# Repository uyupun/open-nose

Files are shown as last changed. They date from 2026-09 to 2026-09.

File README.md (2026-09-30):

# OpenNose

- 鼻栓の民主化プロジェクト
- 鼻に詰めたティッシュ(鼻栓)を、「隠すもの」から「装うもの」へ。鼻栓を、身近なものにする
- 簡略化した鼻モデルと遺伝的アルゴリズム(NSGA-II)で、形のトレードオフ(パレート最適)を探る
- 現在の主案は[水引型](#水引型現在の主案)(`scripts/mizuhiki/`)。鼻ピアス型・ゼンマイ型・拡張ブリッジ型・元の設計は、これまでに試した方向

## 構成

```
scripts/
  commons/     # 設計に依らず共通で使うもの
    nose_model.py        # 簡略化した鼻本体モデル(NoseParams)
    plug_model.py        # 鼻栓(ティッシュ等)のプレースホルダー(PlugParams)
    rounded_triangle.py  # 鼻の断面(角丸三角形)の2D幾何プリミティブ
    viewer.py            # ビューア補助(半透明の描画順・カメラ調整)
    report.py            # NSGA-IIの結果表示(世代推移の図・パレートフロントの表)
  earrings/    # 鼻ピアス型(「b」字)フレーム: 片方の鼻ごとに独立したクリップ
    frame_model.py       # 形状(FrameParamsの6変数): 鼻翼を挟むリング + 鼻栓に刺すステム
    evaluation.py        # 評価関数(3目的 + 制約)
    scene.py             # 鼻本体・鼻栓・フレームを1つのSceneにまとめる
    optimize.py / export_model.py / export_frame.py / view_nose.py
  spiral/      # ゼンマイ(渦巻き)型フレーム: 鼻翼の外側にぶら下がるコイル + 鼻栓に刺すステム
    frame_model.py       # 形状(FrameParamsの6変数): 渦巻きのコイル + ステム
    evaluation.py        # 評価関数(3目的 + 制約)
    scene.py             # 鼻本体・鼻栓・フレームを1つのSceneにまとめる
    optimize.py / export_model.py / export_frame.py / view_nose.py
  dilator/     # 拡張ブリッジ型フレーム: 鼻腔拡張テープ(ブリーズライト等)のように鼻を押し開く平らなブリッジ + 鼻栓を受け入れる筒
    frame_model.py       # 形状(FrameParamsの8変数): 鼻の前面と側面に沿って横断する平らな薄いブリッジ(両端は巻き込まずまっすぐ伸ばし、両面テープの貼り代にする。印刷するときは同じアーチを少し開いた自然な形) + 左右の棒(アーチと同じ板の断面で、アーチの面からリングの面へねじれる平たいブレード。鼻翼の輪郭に沿って鼻孔まで約31mm) + 左右のリング(鼻中隔側を開いたC字の筒)(印刷・装着しやすいよう3部品に分け、脚の上端の小さなC字が帯の上下の縁を抱いて連結する)
    evaluation.py        # 評価関数(3目的: 拡張力・鼻栓の保持剛性・目立たなさ + 制約16個)
    scene.py             # 鼻本体・鼻栓・フレームを1つのSceneにまとめる
    optimize.py / export_model.py / export_frame.py / view_nose.py
  mizuhiki/    # 水引型: 丸めたティッシュ(鼻栓)に着け、3本の紐の帯がティッシュを1周する輪から小鼻の外側へ上がって、あわじ結び(三つ輪)になる器具。結びを小鼻の前寄り(鼻の側面)に置き、正面からも横顔からも水引と読める。濃い色で刷ると、結びが鼻の穴の両脇を縁取り、小鼻の輪郭にも見える
    frame_model.py       # 形状(MizuhikiParamsの5変数: 結びの大きさ・高さ・小鼻の上の位置、紐の太さ、端の長さ)。紐の肌の側をつなぐ板と、輪の底を平らに削る補強でFDMで刷れる
    evaluation.py        # 評価関数(3目的: 横顔での存在感・正面での読みやすさ・ティッシュをつかむ面積 + 制約13個)
    scene.py             # 鼻本体・鼻栓・器具を1つのSceneにまとめる
    optimize.py / export_model.py / export_frame.py / view_nose.py
  models/      # 元の設計: 鼻中隔付近のアーム + 鼻栓へ向かうコネクタ(両鼻を同時に挟む)
    frame_model.py / scene.py
  evaluation.py / optimize.py / optimize_report.py
  export_model.py / export_frame.py / view_nose.py   # 元の設計のスクリプト
output/
  models/    # 元の設計の出力(base.glb, evolution.png, candidate_*.glb)
  earrings/  # 鼻ピアス型の出力(base.glb, evolution.png, candidate_*.glb, 印刷用 *_frame_{left,right}.stl)
  spiral/    # ゼンマイ型の出力(base.glb, evolution.png, candidate_*.glb, 印刷用 *_frame_{left,right}.stl)
  mizuhiki/  # 水引型の出力(base.glb, evolution.png, pareto.csv, candidate_*.glb, 印刷用 *_{left,right}_print.stl)
  dilator/   # 拡張ブリッジ型の出力(base.glb, evolution.png, candidate_*.glb, 印刷用 *_frame_bridge.stl / *_frame_leg_left.stl / *_frame_leg_right.stl)
```

新しい設計を足すときは、`earrings/`と同じ構成(frame_model・evaluation・scene・各スクリプト)のフォルダを`scripts/`直下に作り、鼻本体・鼻栓・ビューア・レポートは`commons/`のものを使う。

## 水引型(現在の主案)

丸めたティッシュ(鼻栓)に着ける小さな器具。3本の紐を平らに並べた帯がティッシュのまわりを1周して輪になり(輪にティッシュを通して留める)、小鼻の外側を上がって、あわじ結び(三つ輪)になる。結びの下からは端が垂れる。

水引は、ご祝儀袋やお見舞いの包みで誰もが目にする結びで、性別を問わず使われる。鼻栓に水引を添えることで、見られたくないものを、見覚えのある贈り物の飾りに変える。ティッシュを通す輪だけの形(鼻の下のキャップ)は人の目に留まらず、見え方を変えられなかったので、結びを小鼻の上に出して見せている。

- **結びの位置**: 小鼻の横ではなく、正面を斜めに向いた鼻の側面に置く。最初の試作を着けてみると、小鼻の横の結びは正面から真横に見えて、三つ輪がつぶれて読めなかった。人に見られるのはほとんど正面からなので、正面から水引と分かる位置に出した。結びの内側の端は、正面から見て鼻の穴の中心の線までに収め、鼻頭には乗せない
- **色**: 濃い色(焦げ茶・濃紺など)で刷ると、結びが鼻の穴の両脇を縁取り、小鼻の輪郭にも見える(見立て)。黒は水引では弔事(黒白)の色なので、描画では焦げ茶にしている
- **大きさ**: 結びの大きさは評価関数では決めず、見た目の塩梅で決める。どの目的も「大きいほど見える」ので、探索させると上限に張り付くため。いまは最初に刷った形の1.1倍(`optimize.py --knot-scale`で変えられる)

### 評価関数(`scripts/mizuhiki/evaluation.py`)

目的は3つで、いずれも大きいほど良い。

| 目的 | 測るもの |
|---|---|
| 横顔での存在感 | 真横から見える、輪より上(渡り・結び・端)の面積 |
| 正面での読みやすさ | 正面から見える、結びと端の面積 |
| ティッシュをつかむ面積 | 輪の内側の面積(紐が太いほど輪が高く、よくつかむ) |

見える面積は、鼻の陰に隠れる部分を除いて測る。結びの位置が小鼻の横に寄るほど横顔で、鼻の側面に寄るほど正面で見え、この向きが1つ目と2つ目のトレードオフになる。

制約は13個で、すべて満たす形だけを候補にする。

- 結びが読める: 三つ輪の穴が、横顔からも正面からも抜けて見える(紐を太く・結びを小さくすると穴が潰れる)
- 鼻頭に乗らない: 正面から見て、結びの内側の端が鼻の穴の中心の線を越えない
- 肌・顔との関係: 紐が肌に近づきすぎない、結びが肌から浮かず小鼻の面に乗る、頬に当たらない、小鼻の上端を越えない、鼻の下へ垂れない、左右の器具が当たらない
- FDM(0.4mmノズル)で刷れる: 紐の直径0.8mm以上、紐のつなぎ目の厚み0.6mm以上、輪の底がベッドに着く面積

閾値はいずれも暫定値で、刷って着けながら見直していく。

### いまのおすすめ

`candidate_frontal`(結びの大きさ1.74・高さ2.30・位置1.30・紐の半径0.455mm)。最初に刷った形(小鼻の横に結び)と比べて、正面での読みやすさが約2.4倍(27.8→67.2mm^2)になり、横顔での存在感はほぼ保っている(85.2→80.5mm^2)。結びの内側の端は、鼻の穴の中心の線の0.65mm手前。

`output/mizuhiki/base.glb`(既定値の形)は、最初に手で決めた形のまま。いまの評価では、結びの後ろの輪が頬に当たり、正面から三つ輪が読めない。

### 刷り方(Bambu Studio・FDM 0.4mmノズル)

試作はPLAで刷っている。器具は左右とも約15×16×14mm、片側約0.2g。

- **STL**: `candidate_frontal_left_print.stl`・`candidate_frontal_right_print.stl`。輪の底面をベッドに置き、着けたときの上を上にした向きで書き出してある(6方向を比べて、サポートの要る面が最も少ない向き)。読み込んだ向きのまま使い、自動配置はしない
- **品質**: 層の高さ0.12mm前後、壁生成はArachne(0.6mm前後の紐のつなぎ目を1本の線に丸めずに出す)
- **ブリム**: 外側のみ、幅3〜5mm。ベッドに着くのは輪の底の細い環だけなので
- **冷却**: 左右を離して並べ、冷却のため速度を落とす設定をオンにする(小さい部品は1層がすぐ終わり、冷えきらずにだれる)
- **サポート**: タイプを「ツリー(手動)」にし、サポートペイント(L)で、次の3か所の紐の下側だけを強制で塗る(左右それぞれ)。どれも真下はベッドまで空いているので、「ビルドプレートのみ」はオンでよい
  - 結びから垂れる端の先(高さ約1.7mm)
  - 結びの下の輪のいちばん下(高さ約3.3mm)
  - 結びの上の輪の張り出し(高さ約8.6〜9.0mm)

  自動にすると、三つ輪の中の1mm前後の橋渡し(支えなしで刷れる)にまで枝が入り込み、外しにくく紐を折りやすい。塗る場所は、一度スライスしてプレビューの層スライダーを上の高さに合わせると、宙に浮いて始まる紐として見つかる
- **サポートの外し方**: 完全に冷めてから、ベッド側の太い幹を先にニッパーで切り、紐に付いた先端は、その紐のすぐ横を押さえて小さく揺らして外す。器具は太い輪の部分を持ち、結びは持たない

## Scripts

### 共通

```bash
# 依存パッケージをインストール
$ uv sync
```

### 鼻ピアス型(earrings)

```bash
# 鼻本体・鼻栓・フレームの既定構成一式を生成して output/earrings/base.glb に出力
$ uv run python scripts/earrings/export_model.py

# 生成した鼻モデルをインタラクティブビューアで確認(引数なしで既定形状)
$ uv run python scripts/earrings/view_nose.py

# NSGA-IIでフレーム形状を最適化し、output/earrings/evolution.png に出力(パレートフロントは標準出力の表で確認)
# --sort-by {retention,pain,visibility} で表の並び順を変えられる(ある目的に極振りした候補を先頭から拾う用)
$ uv run python scripts/earrings/optimize.py
$ uv run python scripts/earrings/optimize.py --sort-by visibility

# 上の表から選んだ行の6変数(ring_r ring_gap ring_t ring_d stem_len stem_t)をglTF(.glb)に出力
# (base.glbは上書きしない。ファイル名は実行時刻から自動生成、--output-nameで指定も可)
$ uv run python scripts/earrings/export_frame.py --ring-radius 3.04 --ring-gap-deg 92.13 --ring-thickness 2.47 --ring-depth 0.85 --stem-length 3.84 --stem-thickness 1.09 --output-name candidate_balanced.glb

# --stl を付けると、フレーム(左右)だけを3Dプリント用STLとしても書き出す
# (output/earrings/<出力名>_frame_left.stl / _frame_right.stl、単位mm)
$ uv run python scripts/earrings/export_frame.py --ring-radius 3.04 --ring-gap-deg 92.13 --ring-thickness 2.47 --ring-depth 0.85 --stem-length 3.84 --stem-thickness 1.09 --output-name candidate_balanced.glb --stl

# 出力した候補(glb)や、フレーム単体のSTLをインタラクティブビューアで確認
$ uv run python scripts/earrings/view_nose.py output/earrings/candidate_balanced.glb
$ uv run python scripts/earrings/view_nose.py output/earrings/candidate_balanced_frame_left.stl
```

### ゼンマイ型(spiral)

```bash
# 鼻本体・鼻栓・フレームの既定構成一式を生成して output/spiral/base.glb に出力
$ uv run python scripts/spiral/export_model.py

# 生成した鼻モデルをインタラクティブビューアで確認(引数なしで既定形状)
$ uv run python scripts/spiral/view_nose.py

# NSGA-IIでフレーム形状を最適化し、output/spiral/evolution.png に出力(パレートフロントは標準出力の表で確認)
# --sort-by {visibility,weight,turns} で表の並び順を変えられる(ある目的に極振りした候補を先頭から拾う用)
$ uv run python scripts/spiral/optimize.py
$ uv run python scripts/spiral/optimize.py --sort-by weight

# 上の表から選んだ行の6変数(turns start_r end_r coil_t stem_t stem_len)をglTF(.glb)に出力
# (base.glbは上書きしない。ファイル名は実行時刻から自動生成、--output-nameで指定も可)
$ uv run python scripts/spiral/export_frame.py --turns 0.73 --start-radius 7.42 --end-radius 2.95 --coil-thickness 1.80 --stem-thickness 0.58 --stem-length 8.06 --output-name candidate_balanced.glb

# --stl を付けると、フレーム(左右)だけを3Dプリント用STLとしても書き出す
# (output/spiral/<出力名>_frame_left.stl / _frame_right.stl、単位mm)
$ uv run python scripts/spiral/export_frame.py --turns 0.73 --start-radius 7.42 --end-radius 2.95 --coil-thickness 1.80 --stem-thickness 0.58 --stem-length 8.06 --output-name candidate_balanced.glb --stl

# 出力した候補(glb)や、フレーム単体のSTLをインタラクティブビューアで確認
$ uv run python scripts/spiral/view_nose.py output/spiral/candidate_balanced.glb
$ uv run python scripts/spiral/view_nose.py output/spiral/candidate_balanced_frame_left.stl
```

### 拡張ブリッジ型(dilator)

```bash
# 鼻本体・鼻栓・フレームの既定構成一式を生成して output/dilator/base.glb に出力
$ uv run python scripts/dilator/export_model.py

# 生成した鼻モデルをインタラクティブビューアで確認(引数なしで既定形状)
$ uv run python scripts/dilator/view_nose.py

# NSGA-IIでフレーム形状を最適化し、output/dilator/evolution.png に出力(パレートフロントは標準出力の表で確認)
# --sort-by {extension_force,plug_hold,inconspicuousness} で表の並び順を変えられる(ある目的に極振りした候補を先頭から拾う用)
$ uv run python scripts/dilator/optimize.py
$ uv run python scripts/dilator/optimize.py --sort-by plug_hold

# 上の表から選んだ行の8変数(nat_r tab_pos bridge_y bridge_w bridge_t leg_t collar_l detent。detentは--cuff-detent)をglTF(.glb)に出力
# (base.glbは上書きしない。ファイル名は実行時刻から自動生成、--output-nameで指定も可)
$ uv run python scripts/dilator/export_frame.py --natural-radius 25.96 --tab-side-ratio 1.20 --bridge-y 14.99 --bridge-width 4.06 --bridge-thickness 1.40 --leg-thickness 3.32 --collar-length 2.08 --cuff-detent 0.12 --output-name candidate_balanced.glb

# --stl を付けると、フレームを3Dプリント用STLとしても書き出す。印刷しやすい
# ように、ブリッジ(鼻筋のアーチ状の帯)・左の脚(棒とリング)・右の脚(棒と
# リング)の3つの別々のファイルになる(output/dilator/<出力名>_frame_bridge.stl・
# _frame_leg_left.stl・_frame_leg_right.stl、単位mm)。ブリッジのSTLは、装着
# した形そのものではなく、同じアーチの曲がりを弱めた(少し開いた)自然な形で、
# 鼻の上で曲げて両端を医療用両面テープで貼ると、曲げ戻ろうとする力がブリーズ
# ライトのように小鼻を引き上げる。帯は鼻の前面の丸みと側面に沿うアーチで、両端は
# 鼻の角に沿って巻き込まず、側面の向きのまままっすぐ伸びる(長さ約27mm)。脚は
# それぞれ別々にプリントし、帯を抱くCで組み立てる: 脚の上端は棒と同じ幅の小さな
# C字で、帯の上下の縁に掘ったV溝に爪を入れて帯を抱く。帯の端から滑り込ませ、端寄りの
# 浅い段をカチッと越えると止まる(テープを貼った後でも付け外しできる。爪は帯の厚みの
# 内側で止まり、肌と帯の間には入らない)。
# 棒は鼻の側面を小鼻の外側の輪郭(鼻翼)に沿って降り、鼻中隔側を開いたC字のリングに
# つながる。この設計では鼻栓は鼻の下端から約6.5mm
# 飛び出している想定で、リングはその露出端を掴む
$ uv run python scripts/dilator/export_frame.py --natural-radius 25.96 --tab-side-ratio 1.20 --bridge-y 14.99 --bridge-width 4.06 --bridge-thickness 1.40 --leg-thickness 3.32 --collar-length 2.08 --cuff-detent 0.12 --output-name candidate_balanced.glb --stl

# 出力した候補(glb)や、部品単体のSTLをインタラクティブビューアで確認
$ uv run python scripts/dilator/view_nose.py output/dilator/candidate_balanced.glb
$ uv run python scripts/dilator/view_nose.py output/dilator/candidate_balanced_frame_bridge.stl
```

### 水引型(mizuhiki)

```bash
# 鼻本体・鼻栓・器具の既定構成一式(最初に手で決めた水引の形)を生成して output/mizuhiki/base.glb に出力
$ uv run python scripts/mizuhiki/export_model.py

# 生成した鼻モデルをインタラクティブビューアで確認(引数なしで既定形状)
$ uv run python scripts/mizuhiki/view_nose.py

# NSGA-IIで結びの高さ・小鼻の上の位置・紐の太さを最適化する(40個体×40世代で約7分)。結びの大きさは
# 探索せず --knot-scale で与える(既定1.74)。目的は横顔での存在感・正面での読みやすさ・ティッシュを
# つかむ面積の3つ、制約は13個(scripts/mizuhiki/evaluation.py)。output/mizuhiki/ に次を出力する:
#   evolution.png(世代ごとの分布推移)、pareto.csv(パレートフロントの全個体の変数・目的・制約)、
#   candidate_presence.glb(横顔での存在感が最大)・candidate_frontal.glb(正面で最も読みやすい)・
#   candidate_balanced.glb(3つの目的をパレートフロントの中で0〜1にそろえ、理想点に最も近いもの。
#   目的の差が小さいと、わずかな差に引っ張られるので、表やpareto.csvと見比べて選ぶ)
# パレートフロントの表は標準出力にも出る。--sort-by {profile_presence,frontal_legibility,tissue_grip} で並び順を変えられる
$ uv run python scripts/mizuhiki/optimize.py
$ uv run python scripts/mizuhiki/optimize.py --knot-scale 1.6

# 設計変数を指定してglTF(.glb)に出力し、評価関数の結果(目的3つと制約13個の合否)を表示する。
# 引数を省略した変数は既定値。上の表やpareto.csvから選んだ行の値を渡す(base.glbは上書きしない。
# ファイル名は実行時刻から自動生成、--output-nameで指定も可)
$ uv run python scripts/mizuhiki/export_frame.py
$ uv run python scripts/mizuhiki/export_frame.py --knot-scale 1.74 --knot-y 2.3006 --knot-f 1.2960 --cord-radius 0.4553 --output-name candidate_frontal

# --print を付けると、器具(左右)をそのまま刷れる向き(輪の底面をベッドに置き、着けたときの上を上にする)の
# STLとしても書き出す(<出力名>_left_print.stl / _right_print.stl、単位mm)。FDM(0.4mmノズル)向けに、並べた
# 紐の肌の側を板でつなぎ(つなぎ目の厚み0.6mm以上)、輪の底を0.2mm平らに削ってある。刷るときはツリー
# サポート(手動で3か所を塗る。上の「刷り方」参照)とブリムを使う。--stl で鼻に着けた向きのSTLも書き出せる
$ uv run python scripts/mizuhiki/export_frame.py --knot-scale 1.74 --knot-y 2.3006 --knot-f 1.2960 --cord-radius 0.4553 --output-name candidate_frontal --print

# 出力した候補(glb)や、器具単体のSTLをインタラクティブビューアで確認
$ uv run python scripts/mizuhiki/view_nose.py output/mizuhiki/candidate_frontal.glb
$ uv run python scripts/mizuhiki/view_nose.py output/mizuhiki/candidate_frontal_right_print.stl
```

### 元の設計(アーム + コネクタ)

```bash
# 鼻本体・鼻栓・フレームの既定構成一式を生成して output/models/base.glb に出力
$ uv run python scripts/export_model.py

# 生成した鼻モデルをインタラクティブビューアで確認
$ uv run python scripts/view_nose.py

# NSGA-IIでフレーム形状を最適化し、output/models/evolution.png に出力(パレートフロントは標準出力の表で確認)
$ uv run python scripts/optimize.py

# 上の表から選んだ候補(11変数)をglTF(.glb)に出力(base.glbは上書きしない)
$ uv run python scripts/export_frame.py --connector-heading 24 --connector-length-1 5.5 --arm-thickness 2.0 --holder-offset 12 --grip-depth 0.5

# 出力した候補をインタラクティブビューアで確認
$ uv run python scripts/view_nose.py output/models/candidate_balanced.glb
```

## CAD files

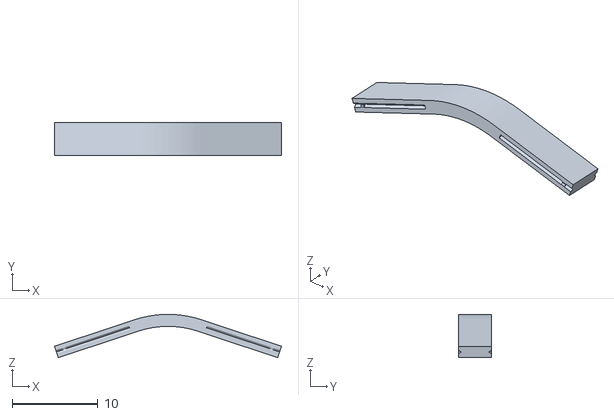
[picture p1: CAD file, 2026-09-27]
output/dilator/connector_cuff_frame_bridge.stl
26.5 x 3.81 x 5.05

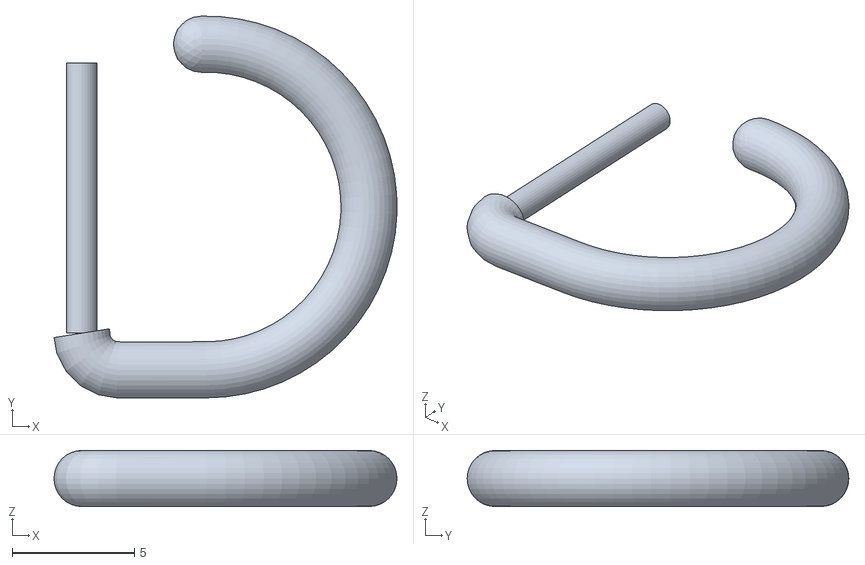
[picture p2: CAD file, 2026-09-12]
output/earrings/candidate_balanced_frame_right.stl
14.0 x 15.6 x 2.30

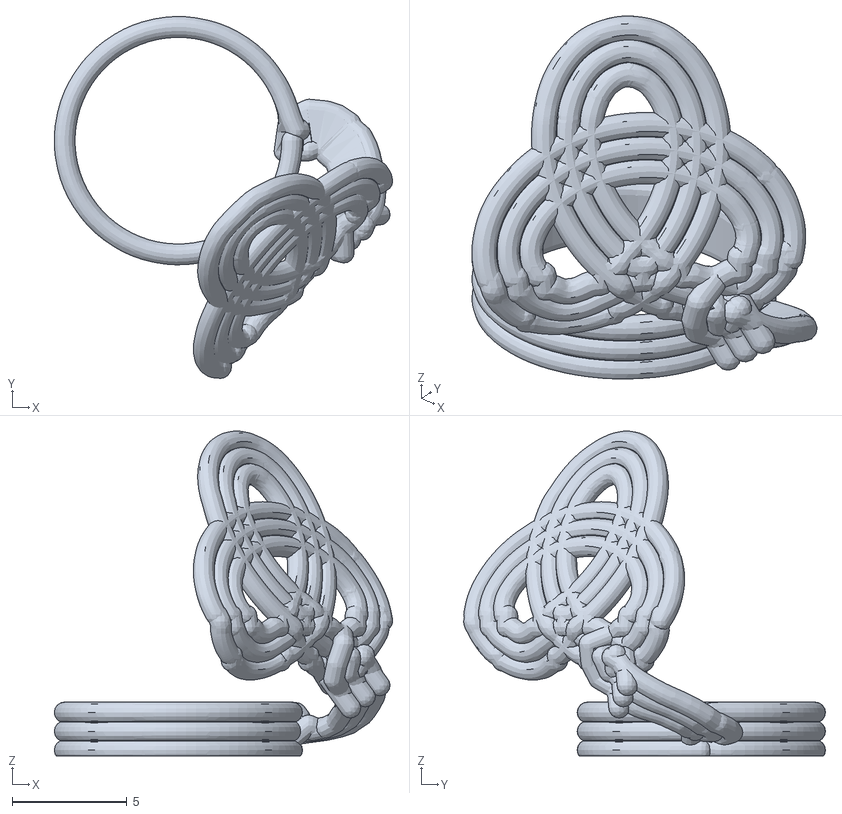
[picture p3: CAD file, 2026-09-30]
output/mizuhiki/candidate_frontal_right_print.stl
14.7 x 15.8 x 14.2

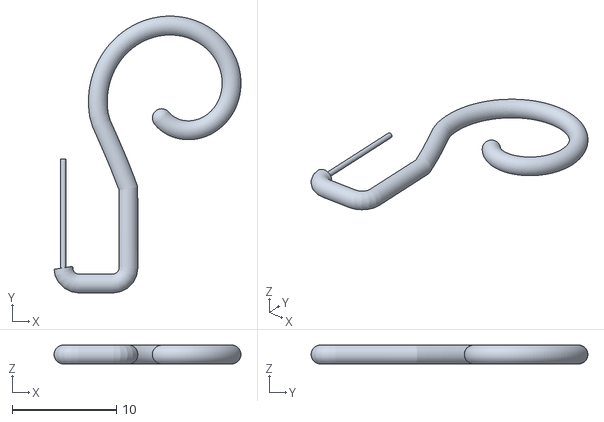
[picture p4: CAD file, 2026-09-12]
output/spiral/candidate_high_visibility_frame_right.stl
17.9 x 26.5 x 1.81

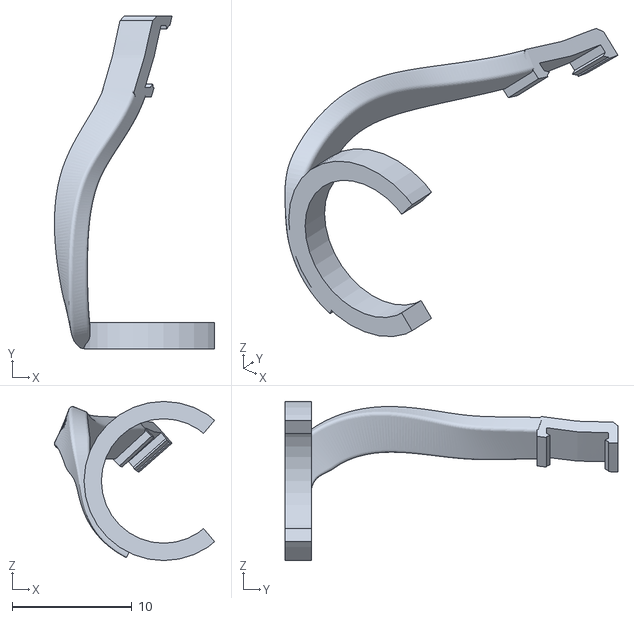
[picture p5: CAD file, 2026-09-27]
output/dilator/candidate_high_force_frame_leg_left.stl
13.4 x 27.8 x 13.3

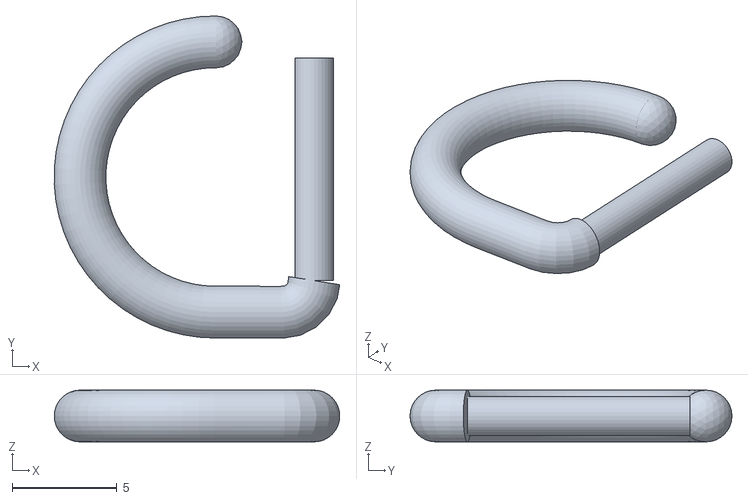
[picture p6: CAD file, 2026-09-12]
output/earrings/candidate_high_retention_frame_left.stl
13.6 x 15.3 x 2.47

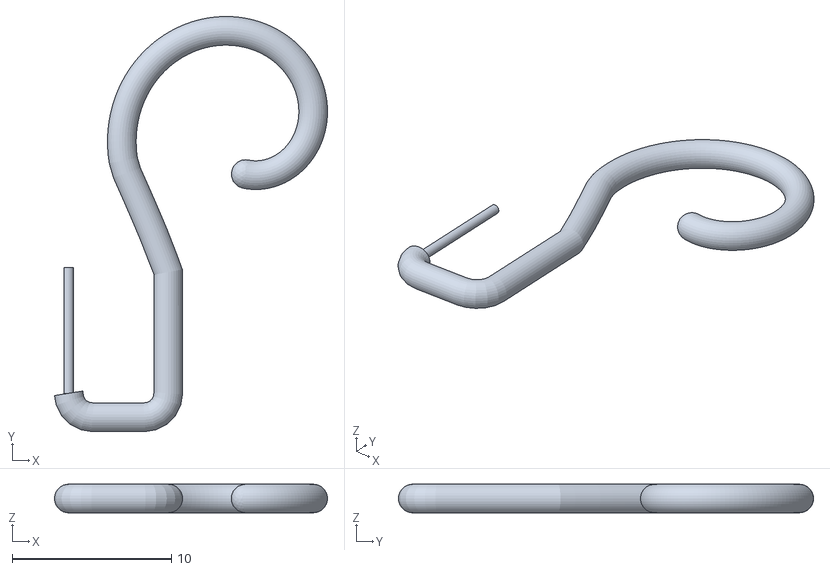
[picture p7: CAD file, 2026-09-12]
output/spiral/candidate_balanced_frame_right.stl
17.1 x 26.0 x 1.80

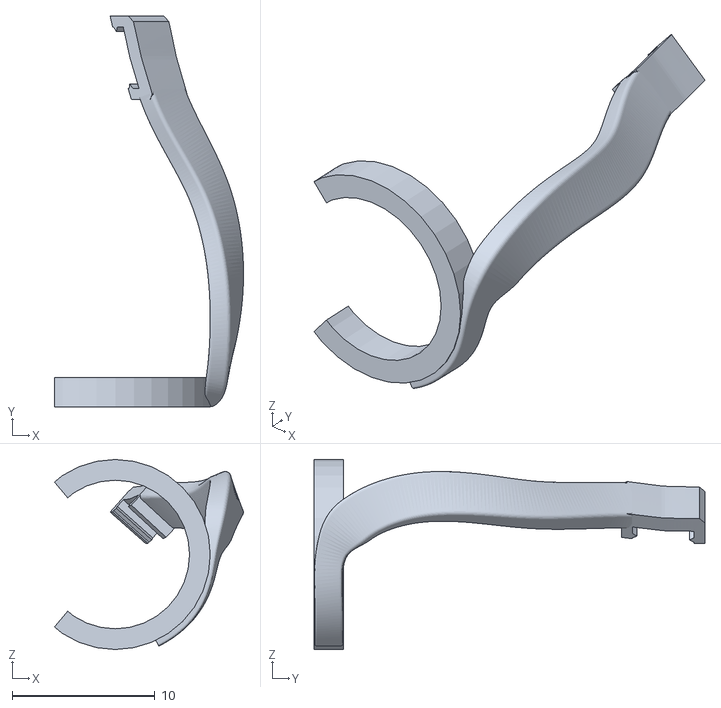
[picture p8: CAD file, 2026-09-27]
output/dilator/candidate_balanced_frame_leg_right.stl
13.2 x 27.4 x 13.3

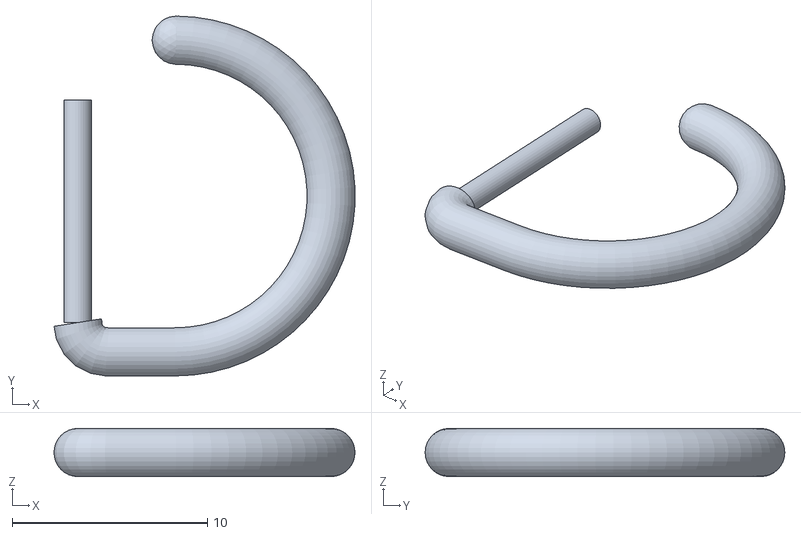
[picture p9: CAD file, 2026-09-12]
output/earrings/candidate_low_pain_frame_right.stl
15.4 x 18.4 x 2.47

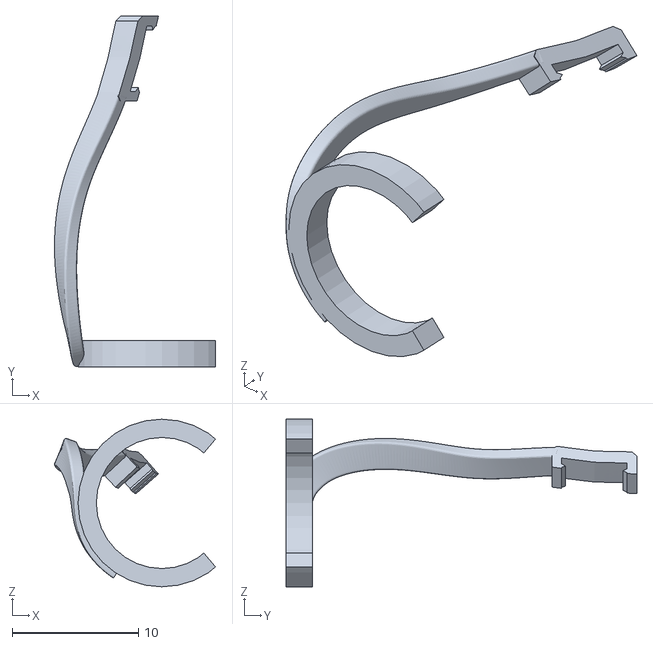
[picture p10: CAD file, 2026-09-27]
output/dilator/candidate_inconspicuous_frame_leg_left.stl
12.8 x 27.8 x 13.3

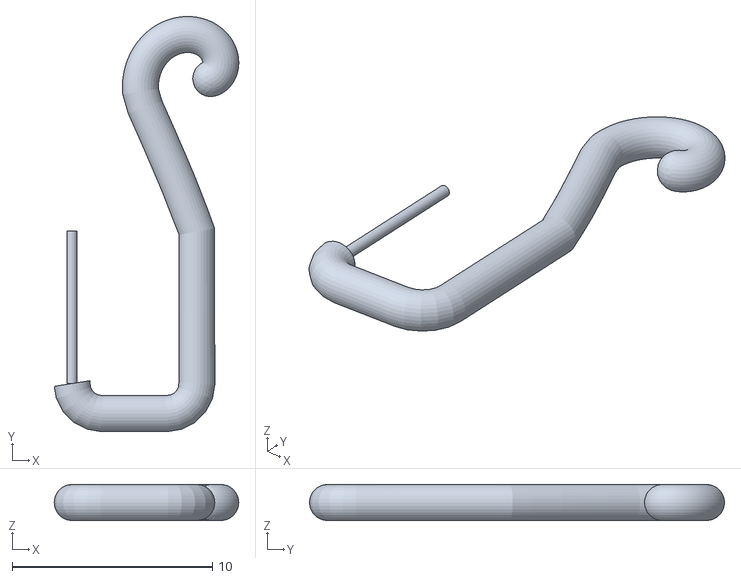
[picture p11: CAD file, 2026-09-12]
output/spiral/candidate_low_weight_frame_right.stl
9.23 x 20.7 x 1.80

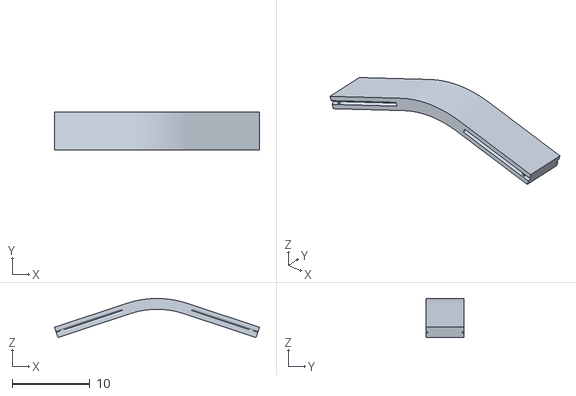
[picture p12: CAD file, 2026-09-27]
output/dilator/candidate_inconspicuous_frame_bridge.stl
26.4 x 4.95 x 5.04

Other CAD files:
output/mizuhiki/candidate_frontal_left_print.stl
output/spiral/candidate_balanced_frame_left.stl
output/earrings/candidate_high_retention_frame_right.stl
output/earrings/candidate_balanced_frame_left.stl
output/spiral/candidate_high_visibility_frame_left.stl
output/dilator/candidate_high_force_frame_leg_right.stl
output/dilator/candidate_balanced_frame_bridge.stl
output/dilator/candidate_balanced_frame_leg_left.stl
output/dilator/candidate_high_force_frame_bridge.stl
output/dilator/candidate_inconspicuous_frame_leg_right.stl
output/dilator/connector_cuff_frame_leg_left.stl
output/dilator/connector_cuff_frame_leg_right.stl
output/earrings/candidate_low_pain_frame_left.stl
output/spiral/candidate_low_weight_frame_left.stl

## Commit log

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2026-09-03 Rework nose model as a filleted-triangle cross-section
    Replace the superellipse (rounded-rectangle) cross-section with a
    filleted-triangle one so the body reads as a triangular prism from
    any viewing angle, not just straight-on. Nostrils are now boolean-
    subtracted from the body (real holes, angled outward) instead of
    placed as separate ellipsoid meshes, positioned/sized to stay within
    the tapered cross-section and not overlap each other.
    Add NoseParams validation (frozen dataclass, positivity/margin
    checks) and structural safety nets (fillet-radius clamping to avoid
    self-intersecting corners, nostril-overlap and empty-mesh guards)
    so invalid or extreme parameter tuning fails loudly instead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
    [nose.obj]
2026-09-03 Round the nose tip cap into the side surface
    The tip's final loft ring was capped directly with a flat fan at its
    full (widest) size, so the nostril openings sat on what looked like a
    flat plate glued onto the body instead of blending from the side. Add
    a quarter-circle rounding transition (a handful of shrinking rings)
    between that ring and the cap, mirroring the existing 2D corner-fillet
    approach.
    Also fix a winding-inversion bug the new rounding introduced (small
    tip_depth_front values caused the shrunk ring's front vertex to cross
    past the back edge), dedupe the 2D-ring-to-3D-vertices step shared by
    the main loft and the new fillet rings, and move the new constants
    next to the other bod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
    [nose.obj]
2026-09-03 Tune nostril tilt, size, and spacing
    Increase nostril_tilt_deg (35 -> 58) so the openings read as more
    vertical in the bottom view, enlarge nostril_a/nostril_b for a more
    realistic size, and pull nostril_gap in (8.0 -> 7.0). Tilt was pushed
    further than initially needed to make room for the larger ellipses
    without triggering the existing overlap guard, since gap and size
    alone left too little clearance.
    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
    [nose.obj]
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2026-09-03 Move nostrils toward the tip, enlarge them, and thin the surrounding wall
    Move nostrils forward (_NOSTRIL_Z_RATIO 0.47 -> 0.58) and enlarge them
    (nostril_a/b), raising nostril_tilt_deg (58 -> 66) to keep clear of
    the existing overlap guard at the same gap.
    The area around the nostrils still read as too thick. Toning down the
    alae bump (_ALAE_BUMP_RATIO 0.35 -> 0.1) helped some, but the bulk of
    it came from tip_w being wide relative to how far the nostril actually
    reaches laterally, so narrow it (34 -> 30).
    Pushing tip_w down further (tried 28) let the nostril ellipsoid punch
    through the side, turning each dimple into a tunnel - the closed
    surface's euler_number flipped from 2 to -2, invisi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
    [nose.obj]
2026-09-03 Scale nose to match 28-year-old Japanese male average proportions
    Anthropometric data (AIST 1991-92 body dimension database) puts
    18-34yo Japanese male nasal height at 52.2mm and nasal width at
    36.2mm, versus the model's previous 45.0mm/30.0mm - shorter and
    narrower than average, not longer as initially assumed.
    Rather than retargeting width independently (which would have
    reopened the wall-thickness issue just fixed), scale every length
    dimension - NoseParams fields, plus the absolute-length module
    constants _BACK_DEPTH/_TIP_BUMP_SPAN/_ALAE_BUMP_SPAN - by the same
    1.16 factor (52.2/45.0) derived from the length match. Ratio-based
    constants need no change since they scale automatically thro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
    [nose.obj]
2026-09-03 Ground nostril and depth proportions in anthropometric data
    Add a root-waist bump (mirroring the existing tip/alae bump pattern)
    so the back surface pinches in near the bridge instead of reading as
    a flat slab glued to the face. Chasing that revealed the real issue
    was elsewhere: a 7.29mm gap between the nostril and the back surface,
    caused by the cross-section's front-to-back depth being oversized
    relative to the nostril.
    Rather than keep repositioning the nostril within an oversized
    triangle, resize the triangle itself. Anthropometric data (nasion
    projection ~4.3mm, pronasale projection ~22.9mm) shows the bridge-end
    depth was already accurate but the tip-end depth was arbitrary and
    too de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
    [nose.obj]
2026-09-03 Give the cross-section a boomerang-shaped back edge
    Real nose cross-sections aren't a flat-backed triangle - the back
    edge dips forward at the septum instead of running straight between
    the two back corners. Replace that straight edge with a concave
    curve (_boomerang_bow) in _rounded_triangle_ring.
    A plain circular arc (matching chord endpoints and a sagitta) left a
    visible kink where it met the adjacent corner fillets, since its
    endpoint tangents didn't match the fillets' horizontal tangent.
    Switched to the same raised-cosine shape already used by
    _localized_bump, which has zero slope at both ends by construction
    and so blends smoothly (G1) instead. Also clamp the bow depth to the
    availabl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
    [nose.obj]
2026-09-03 Add nose plug placeholder cylinder
    Places a simple cylinder inside each nostril as a stand-in for the
    disposable plug, per PROJECT.md's minimal-experiment plan. Size and
    y-offset were tuned interactively to avoid visibly poking through the
    nose surface.
    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
    [nose.obj]
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2026-09-03 Add compact nose-tip frame clip placeholder
    Model the frame as a small clip that stays entirely near the nose tip
    (like a real nose clip), instead of reaching up to the bridge like
    glasses. The arm and its connector to the plug hug the nose's front
    surface profile (including the tip's rounding) to avoid piercing the
    nose body while staying close to it.
    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
    [nose.obj]
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2026-09-04 Add frame evaluation functions (function/comfort/style)
    Introduces evaluate_frame() with three axes (retention/pain/style
    sub-metrics) plus a reach constraint, matching PROJECT.md's v2 design.
    Also fixes several geometry bugs found while building this out: the
    arm anchor referenced the pre-fillet nose surface (so grip_depth never
    actually reached the mesh at default values), cylinder radius wasn't
    accounted for in surface clearance, and validation used unsigned
    distance where sign (inside/outside) mattered. Refactored frame_model
    to share per-side path computation (build_side_paths) instead of
    recomputing it in every caller.
    Claude-Ses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
    [nose.obj]
2026-09-04 Restructure FrameScore into 3 objectives + 4 constraints
    Splits the former 7 unweighted values into retention/pain/fit_gap as
    genuine trade-offs (what NSGA-II should search over) and reach_gap/
    fit_gap_max/smoothness/proportion_penalty as feasibility constraints
    (pass/fail thresholds, not worth deliberately trading off). This
    removes the need to invent cross-domain weights for combining
    sub-metrics into 3 objectives, since only 3 of the 7 values were ever
    genuine trade-offs to begin with.
    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
2026-09-04 Split frame-dependent validation into margins + raising wrappers
    grip_depth/arm_clearance/grip_ring checks now have a *_margin function
    (returns a signed violation amount, no exception) alongside the
    existing validate_* (raises ValueError). build_frame_pair keeps using
    the raising versions since it needs to hard-fail on invalid meshes;
    evaluate_frame now uses the margins directly as three more FrameScore
    constraint fields instead of raising, so a single bad individual won't
    halt a GA's batch evaluation loop.
    validate_target_reach/validate_anchor_height are left untouched (they
    only depend on PlugParams/NoseParams, not the GA's search variables,
    so they can't vary per individual and should s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
2026-09-04 Cache nose body construction and speed up proximity queries
    evaluate_frame previously took ~1.5s per call, which would make a real
    NSGA-II run impractical. Two changes address this:
    - build_nose_body is now cached with functools.lru_cache (NoseParams
    is fixed across a GA run), returning a .copy() so callers can still
    mutate their own instance without corrupting the cache.
    - Profiling showed the actual dominant cost was arm_clearance_margin's
    brute-force nearest-triangle search, not body construction. Tried
    two approximations (sparse ring sampling, coarser cylinder tessellation)
    but both produced measurably wrong margins on some parameter
    combinations, including at least one sign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
2026-09-04 Add NSGA-II optimization over frame parameters (pymoo)
    Wraps evaluate_frame/constraint_values in a pymoo Problem and runs NSGA2
    over the 5 FrameParams variables. Visualization/reporting (generation-
    by-generation objective-space scatter, Pareto table) lives in a separate
    optimize_report.py so the run itself has no matplotlib dependency.
    [nose.obj]
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2026-09-04 Make the arm actually hug the nose surface (arch-style retention)
    Previously only the arm's origin point embedded into the nose; the rest
    of the arm floated off-surface due to a geometry bug where off-center
    points used the centerline's worst-case front boundary instead of the
    actual local surface. Fix arm_points to embed the whole arm by
    grip_depth, add front_surface_z_at_offset/surface_profile_at for
    accurate off-center and tip-cap (y<0) surface positions, generalize
    grip_depth_margin/grip_ring_margin to check the whole arm instead of
    just the origin, and make retention scale with arm_length so the GA
    has a real incentive to explore contact length (previously stuck at
    its floor since nothi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
2026-09-04 Generalize smoothness constraint and rebuild frame as a single tube
    Widen the smoothness constraint from checking only the connector's dive
    transition to every joint along the full arm+connector path, since it was
    missing sharp bends at the arm-connector junction (up to 145 degrees).
    Also replace the frame mesh generation (independent capped cylinders
    concatenated per segment) with trimesh.creation.sweep_polygon, producing
    a single continuous watertight tube instead of ~29 disconnected pieces.
    Remove the separate holder sphere and its holder_size_penalty constraint,
    since the connector's own end cap already reaches the plug's exposed end
    (via reach_gap) and nothing else depended on the sphe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
2026-09-04 Smooth the arm-connector transition by fixing an x-blind surface bug
    connector_points computed its standoff z purely from y, ignoring x, so
    off-center points (which drift outward from the arm end) used the
    centermost/most-forward surface value instead of the correct one for
    their actual x. This made the connector float 3.9-4.7mm further from
    the surface than intended, and switching from the arm's embedded z to
    the connector's over-floated z at a single point produced the sharpest
    bend on the whole path (94-108 degrees at the tip).
    Fix connector_points to use the x-aware front_surface_z_at_offset (already
    used by arm_points), and blend the z-offset from -grip_depth to +standoff
    over _STANDOF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
2026-09-04 Make retention scale with clip_angle via the arm's actual path length
    _retention multiplied by frame.arm_length, which is constant regardless
    of clip_angle since it's just the y-span of the arm. Pareto-optimal
    candidates kept clip_angle at 1-6 degrees because widening it never
    improved retention, so the GA had no reason to spread the arm toward
    the alae as originally intended.
    Replace frame.arm_length with the arm's actual 3D path length (from
    arm_points), which grows with clip_angle as the arm spreads outward.
    This keeps the existing judgment that the origin's angle itself doesn't
    generate pinching force intact, while still rewarding a wider spread
    through the surface-area proxy. Bounded b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
2026-09-04 Consolidate accumulated docstrings and drop dangling PROJECT.md references
    Docstrings in evaluation.py and frame_model.py had grown by piling up a
    new "why we changed X" paragraph on every fix without removing the one
    it superseded (e.g. two separate sections for "multiply retention by
    arm_length" and its later replacement by actual path length). Rewrite
    these to describe only the current design, cutting evaluation.py by
    15% and trimming frame_model.py's most bloated docstrings.
    Also remove every docstring/comment reference to PROJECT.md across the
    scripts, since it's intentionally untracked and never committed — those
    pointers would be dead for anyone else who clones the repo. Fold the
    r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
2026-09-04 Free the arm's anchor, direction, and bend count (issue #3)
    FrameParams.clip_angle/arm_length (a fixed anchor y, single-direction
    straight arm) are replaced with anchor_y and a 4-segment turtle-graphics
    path (arm_heading, arm_length_1..4, arm_turn_2..4), so the GA can search
    where the arm starts, which way it points, how many times it bends, and
    which direction each bend goes (5 -> 12 search variables). anchor_y is
    now frame-dependent, so validate_anchor_height moves from an unconditional
    exception to an anchor_height_margin constraint like the other frame-
    dependent checks (7 -> 8 constraints).
    Claude-Session: https://claude.ai/code/s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
2026-09-04 Move arm bending freedom to the connector; fix a transition-safety bug
    The multi-segment bending added for issue #3 lived on the arm, but (1)
    retention only needs a fixed contact length, not bending, and (2) the
    connector's straight shot to the target is what actually determines the
    frame's visible shape. Worse, the arm's flat-surface approximations
    (grip_depth_margin/grip_ring_margin) silently missed real penetration
    once bending pushed the arm far from its assumed near-straight path
    (measured up to 4.2mm of undetected embedding). So the arm reverts to a
    fixed shape (_ARM_ANCHOR_Y/_ARM_HEADING/_ARM_LENGTH) and the connector
    gains the 4-segment turtle-graphics freedom instead, where safety i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
2026-09-04 Fix the dive-segment safety gap and a signed-distance sign error
    connector_points' final "dive" to the plug's exposed end (target) was
    only ever checked at its centerline (validate_target_reach: target.y
    outside the mesh). The tube itself has radius, and since the dive
    direction is almost entirely along z (closing the gap between the
    surface-hugging connector height and the plug's actual depth), the
    end cap swings nearly its full radius in y -- with the default
    PlugParams/NoseParams, target.y cleared the mesh boundary by only
    0.25mm, so anything above arm_thickness=0.5mm punched through. Fixed
    by giving PlugParams.length more room (8.0 -> 12.0mm, pushing the
    exposed end further out) and incl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
2026-09-10 Add shared viewer helpers and make the nose and plug more translucent
    trimesh's viewer draws translucent meshes in registration order with depth
    writes enabled, so anything drawn behind an earlier mesh is culled outright
    and no alpha value can reveal it. commons.viewer provides order_for_viewer
    (inner parts first; also needed after loading a glTF, whose node order is
    not preserved), load_for_viewer, and show_scene with a camera offset that
    scales with the scene size (a fixed -8mm pushed small frame-only STLs off
    screen). The nose body (alpha 210->140) and plug (200->80) are made more
    translucent so a stem running inside the nostril stays visible.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
2026-09-10 Add the earrings evaluation: clamp force, skin pressure, and fit
    retention models the clip as a C-ring spring (stiffness ~ wire^4 /
    radius^3) times the deflection ring_depth; pain is that force divided by
    the measured skin-contact area, so a thicker wire raises both and thickness
    becomes a real trade-off instead of pinning at the search bound. fit_gap
    measures how closely the upper arc follows the ala. Stem insertion is a
    minimum-length constraint rather than a retention term, and a hoop
    visibility constraint keeps the GA from hiding the ring inside the nostril.
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2026-09-12 Make report.py's sort keys a caller-supplied parameter
    print_summary took a hardcoded SORT_KEYS dict keyed by the
    connector-freedom design's objective names (including "fit_gap",
    which the earrings design doesn't have). Turn it into a SortKeys
    type and a required sort_keys parameter instead, so each design's
    optimize.py supplies its own objective names/directions and
    report.py stays design-agnostic, matching plot_evolution's existing
    labels parameter.
2026-09-12 Redesign the earrings frame as a hook and require a real nose gap
    frame_model.py's ring is no longer a plain circle: it's a hook (big
    arc around the ala, a straight run under the nose, a small fillet)
    so the ring connects into the stem instead of the stem crossing the
    ring's interior at an angle, and the stem now enters the plug from
    directly below it (matching the user's sketch) rather than at a
    diagonal. The ring's far end is rounded (a unioned hemisphere) and
    kept _MIN_HOOK_GAP away from the stem so the two don't crowd each
    other.
    evaluation.py's third objective is now visibility (how far the hoop
    protrudes past the skin, maximized) instead of fit_gap (how closely
    the upper arc hugs the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
2026-09-12 Regenerate earrings outputs for the hook shape and gap constraint
    base.glb (default FrameParams), evolution.png, and the three
    Pareto-front candidate exports (high_retention/balanced/low_pain,
    each with printable frame STLs) all reflect the hook geometry and
    the corrected ring_clearance_margin from the previous commit.
    [candidate_balanced_frame_left.stl, candidate_balanced_frame_right.stl, candidate_high_retention_frame_left.stl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]
2026-09-12 Add the spiral frame model: a coil hanging off the ala
    New design (scripts/spiral/), started per the user's sketch: instead
    of earrings' clip-style ring, the decorative part is a flat
    Archimedean spiral (like a watch spring) that starts at an anchor
    point on the ala's skin and coils outward/upward for FrameParams.turns
    revolutions while its radius shrinks from start_radius to end_radius.
    The stem-into-the-plug half is unchanged in spirit from earrings
    (frame_model.py's module docstring "幾何" section) - from the same
    anchor, a connector drops to a fixed height below the plug's exposed
    face, runs inward, and fillets up into the stem - but the connector's
    bottom height is now derived directl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
2026-09-12 Add the spiral evaluation: visibility, weight, and turns
    Three objectives instead of earrings' retention/pain/visibility,
    since the spiral has no clamping mechanism to generate a retention
    force from (frame_model.py's module docstring explains why). visibility
    (how far the coil pokes out past the skin) and turns (the coil's own
    winding count) are both maximized and both independently push weight
    (the wire's volume, minimized) up, giving three genuinely competing
    objectives rather than reusing retention/pain's now-inapplicable
    spring model. Constraints carry over what still applies from earrings
    (coil/stem clearance from the nose mesh, plug insertion depth and
    overshoot) plus one new one, rad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
2026-09-12 Make the spiral coil follow the ala before curling, and thicken it
    Three rounds of feedback on the initial coil-from-a-single-anchor
    shape:
    - The coil used to start curling immediately at a fixed-height anchor
    point. Add a segment (_follow_points) that traces the actual ala
    skin contour (sampling _skin_x, not an analytic curve) from
    _FOLLOW_START_Y up to _FOLLOW_END_Y before the spiral begins, so the
    frame visibly hugs the nose for a while first, like the earrings
    hook does, rather than curling right where it meets the skin.
    - That follow segment met the spiral at a fixed direction
    (center placed at a hardcoded +x offset from the anchor), which
    didn't match the follow segment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
2026-09-20 Rebuild the dilator as 3 press-fit pieces; fix the nose model's scale
    The dilator is now a flat bridge that crosses the nose, two rods that
    follow the nose's sides, and two lenses (tubes) that hold the plugs.
    The three pieces print separately and press together with an arrow tab
    and a slot, like a jigsaw floor mat.
    Sized from feedback after actually printing the parts: the rods reach
    the nostrils (bridge raised to y=14, rods 26mm), everything is thick
    enough to print (rods 2.8-3.8mm, arch/tab 2.4-3.4mm, thinnest point of
    a rod 1.98mm), and the lens hole takes a real rolled tissue (10.4mm).
    Fixing that hole exposed three bugs in the geometry and one in the nose
    model itself:
    - The corner r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
    [candidate_balanced_frame.stl, candidate_balanced_frame_bridge.stl, candidate_balanced_frame_leg_left.stl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]
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2026-09-26 Keep the dilator's arch a constant arc and print it in its natural shape
    - Bridge: a constant-curvature arc whose ends reach into the nose's back
    corner (tab_side_ratio > 1) instead of curling along the outline; the
    bridge STL is now the natural (flatter) arc so bending it onto the nose
    gives the Breathe Right-style preload
    - Clip: lead-in chamfers, larger clearance, dome bump and countersunk
    hole; bent along the band's per-height arcs
    - Legs: plug sits 3mm further out of the nostril (DILATOR_PLUG), rod start
    follows the floating arc, blade built as a single loft
    - Mesh cleanup: snap float32 near-duplicates only when needed
    - Re-ran the GA and re-exported the three candidates
    Co-A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
    [candidate_balanced_frame_bridge.stl, candidate_balanced_frame_leg_left.stl, candidate_balanced_frame_leg_right.stl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]
2026-09-27 Join the dilator's legs with a band-hugging C and re-optimize around it
    - Arch: back to following the nose's front curve and flat sides, with the
    ends extended straight instead of curling into the back corner; lifted
    where the real mesh bulges past the analytic section. The printed bridge
    keeps the same arch, opened by actual_radius/natural_radius
    - Connector: the leg's top is a small C (same width as the blade) that
    hugs the band's upper and lower edges, its ridges riding in V-grooves
    cut into the edges; it slides on from the band end and clicks past a
    ramped shallow step. Replaces the edge clip; the connector is
    bent along the band's per-height profiles with finely split edge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
    [candidate_balanced_frame_bridge.stl, candidate_balanced_frame_leg_left.stl, candidate_balanced_frame_leg_right.stl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]
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2026-09-30 Move the mizuhiki knot forward so it reads from the front
    Worn, the first print showed its problem at once: the knot sat on the
    side of the ala, so from the front it was seen edge-on and the three
    loops collapsed into a white squiggle. People mostly see a face from
    the front, so the evaluation now rewards frontal legibility (the knot's
    visible area from the front) instead of frontal restraint, and adds two
    constraints: the three loops must show as open holes from the front
    too, and the knot's inner edge must not cross the line through the
    nostril center when seen from the front, which is where the user drew
    the limit on the render.
    To get there the knot can now sit past the ala's rounded co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
    [candidate_balanced_left_print.stl, candidate_balanced_right_print.stl, candidate_frontal_left_print.stl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]
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
